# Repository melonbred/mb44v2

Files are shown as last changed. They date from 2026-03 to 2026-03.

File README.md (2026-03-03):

# MB-44 v2

MB-44 v2 Hero

## Introduction

The MB-44 is a 12.75u layout 0.5u blocker separating spacebars from the arrow cluster similar to typical 65% layout.

Version 2 is a refresh of the original project that ran in April 2021, updating the case and PCB design.

This repository includes resources for the PCB mainboard and switch plate for the MB-44 v2. Assets of the case are also available for render purposes only and are not intended for manufacturing.

## Improvements

The following are improvements made to the original MB-44:

- Effective key height (EKH) reduced from 24.6mm to 22.2mm
- PCB updated to STM32 from ATmega MCU.
- Updated from C3 variant of the Unified Daughter Board (UDB) to the S1 variant.
- PCB and bottom case cavity reduced to eliminate unnecessary reverberations.
- Brass interior cover plate and accent weight to provide some sound dampening and cover for the UDB cable.
- Plate mounting uses Geon's tadpoles.

## Keyboard Layout

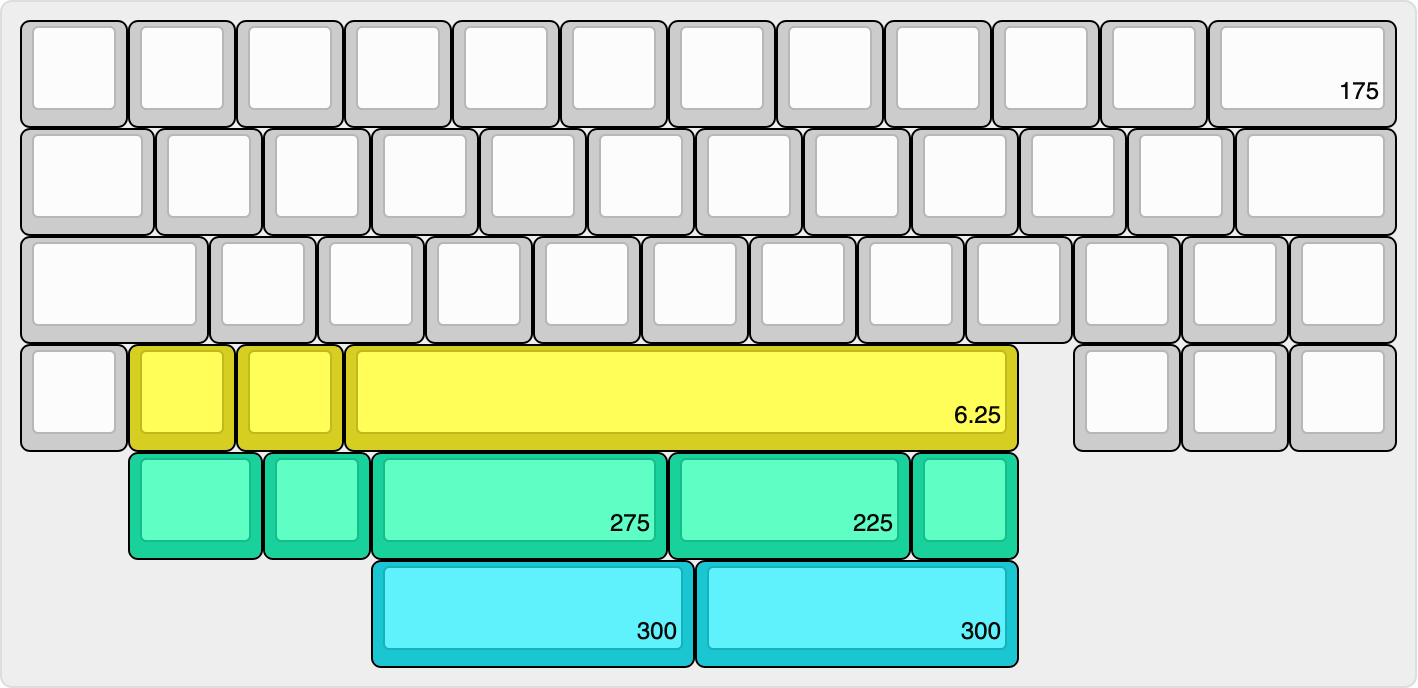
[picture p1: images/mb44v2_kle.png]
MB-44 v2 Keyboard Layout


## Information

Please note that users that would intend to use the resources in this repository is shall review all files prior to any sort of production or manufacturing. The author of this repository does not provide warranty and has no liability for how these resources are used.

Vial firmware has been compiled for for the PCB included in this repository. Firmware source is available [here](https://github.com/vial-kb/vial-qmk/tree/vial/keyboards/melonbred/mb44v2).

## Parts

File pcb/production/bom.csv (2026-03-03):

Designator | Footprint | Quantity | Value | LCSC Part #
C1, C2, C3, C4, C8, C9 | 402 | 6 | 100nF | C307331
C5 | 402 | 1 | 4.7uF | C23733
C6, C7 | 402 | 2 | 1uF | C52923
D1, D10, D11, D12, D13, D14, D15, D16, D17, D18, D19, D2, D20, D21, D22, D23, D24, D25, D26, D27, D28, D29, D3, D30, D31, D32, D33, D34, D35, D36, D37, D38, D39, D4, D40, D41, D42, D43, D46, D47, D48, D5, D6, D7, D8, D9 | D_SOD-523 | 46 | D_Small | C727112
J1 | Molex_Pico-EZmate_78171-0004_1x04-1MP_P1.20mm_Vertical | 1 | Conn_01x04_MountingPin | C528030
R1 | 402 | 1 | 10k | C25744
SW1, SW2 | SW_SPST_SKQG_WithStem | 2 | SW_Push | C318884
U1 | LQFP-48_7x7mm_P0.5mm | 1 | STM32F072CBTx | C81720
U2 | SOT-23-3 | 1 | XC6206PxxxMR | C5446

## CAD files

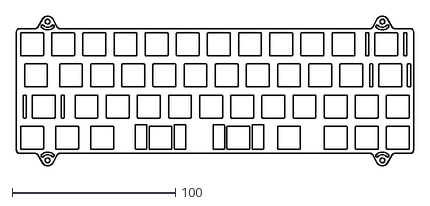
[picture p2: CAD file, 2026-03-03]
plate/mb44v2_plate_275200.dxf
242.9 x 91.7

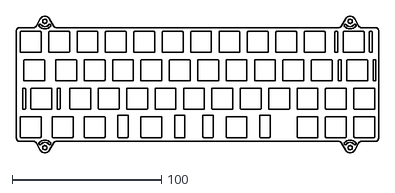
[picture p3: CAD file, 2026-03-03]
plate/mb44v2_plate_300.dxf
242.9 x 91.7

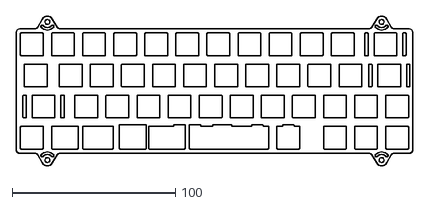
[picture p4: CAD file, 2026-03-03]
plate/mb44v2_plate_universal.dxf
242.9 x 91.7

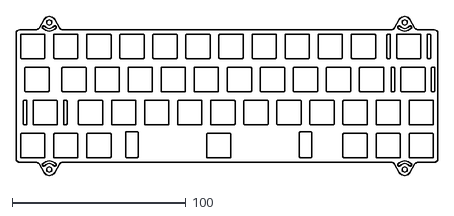
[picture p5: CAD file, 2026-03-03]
plate/mb44v2_plate_625.dxf
242.9 x 91.7

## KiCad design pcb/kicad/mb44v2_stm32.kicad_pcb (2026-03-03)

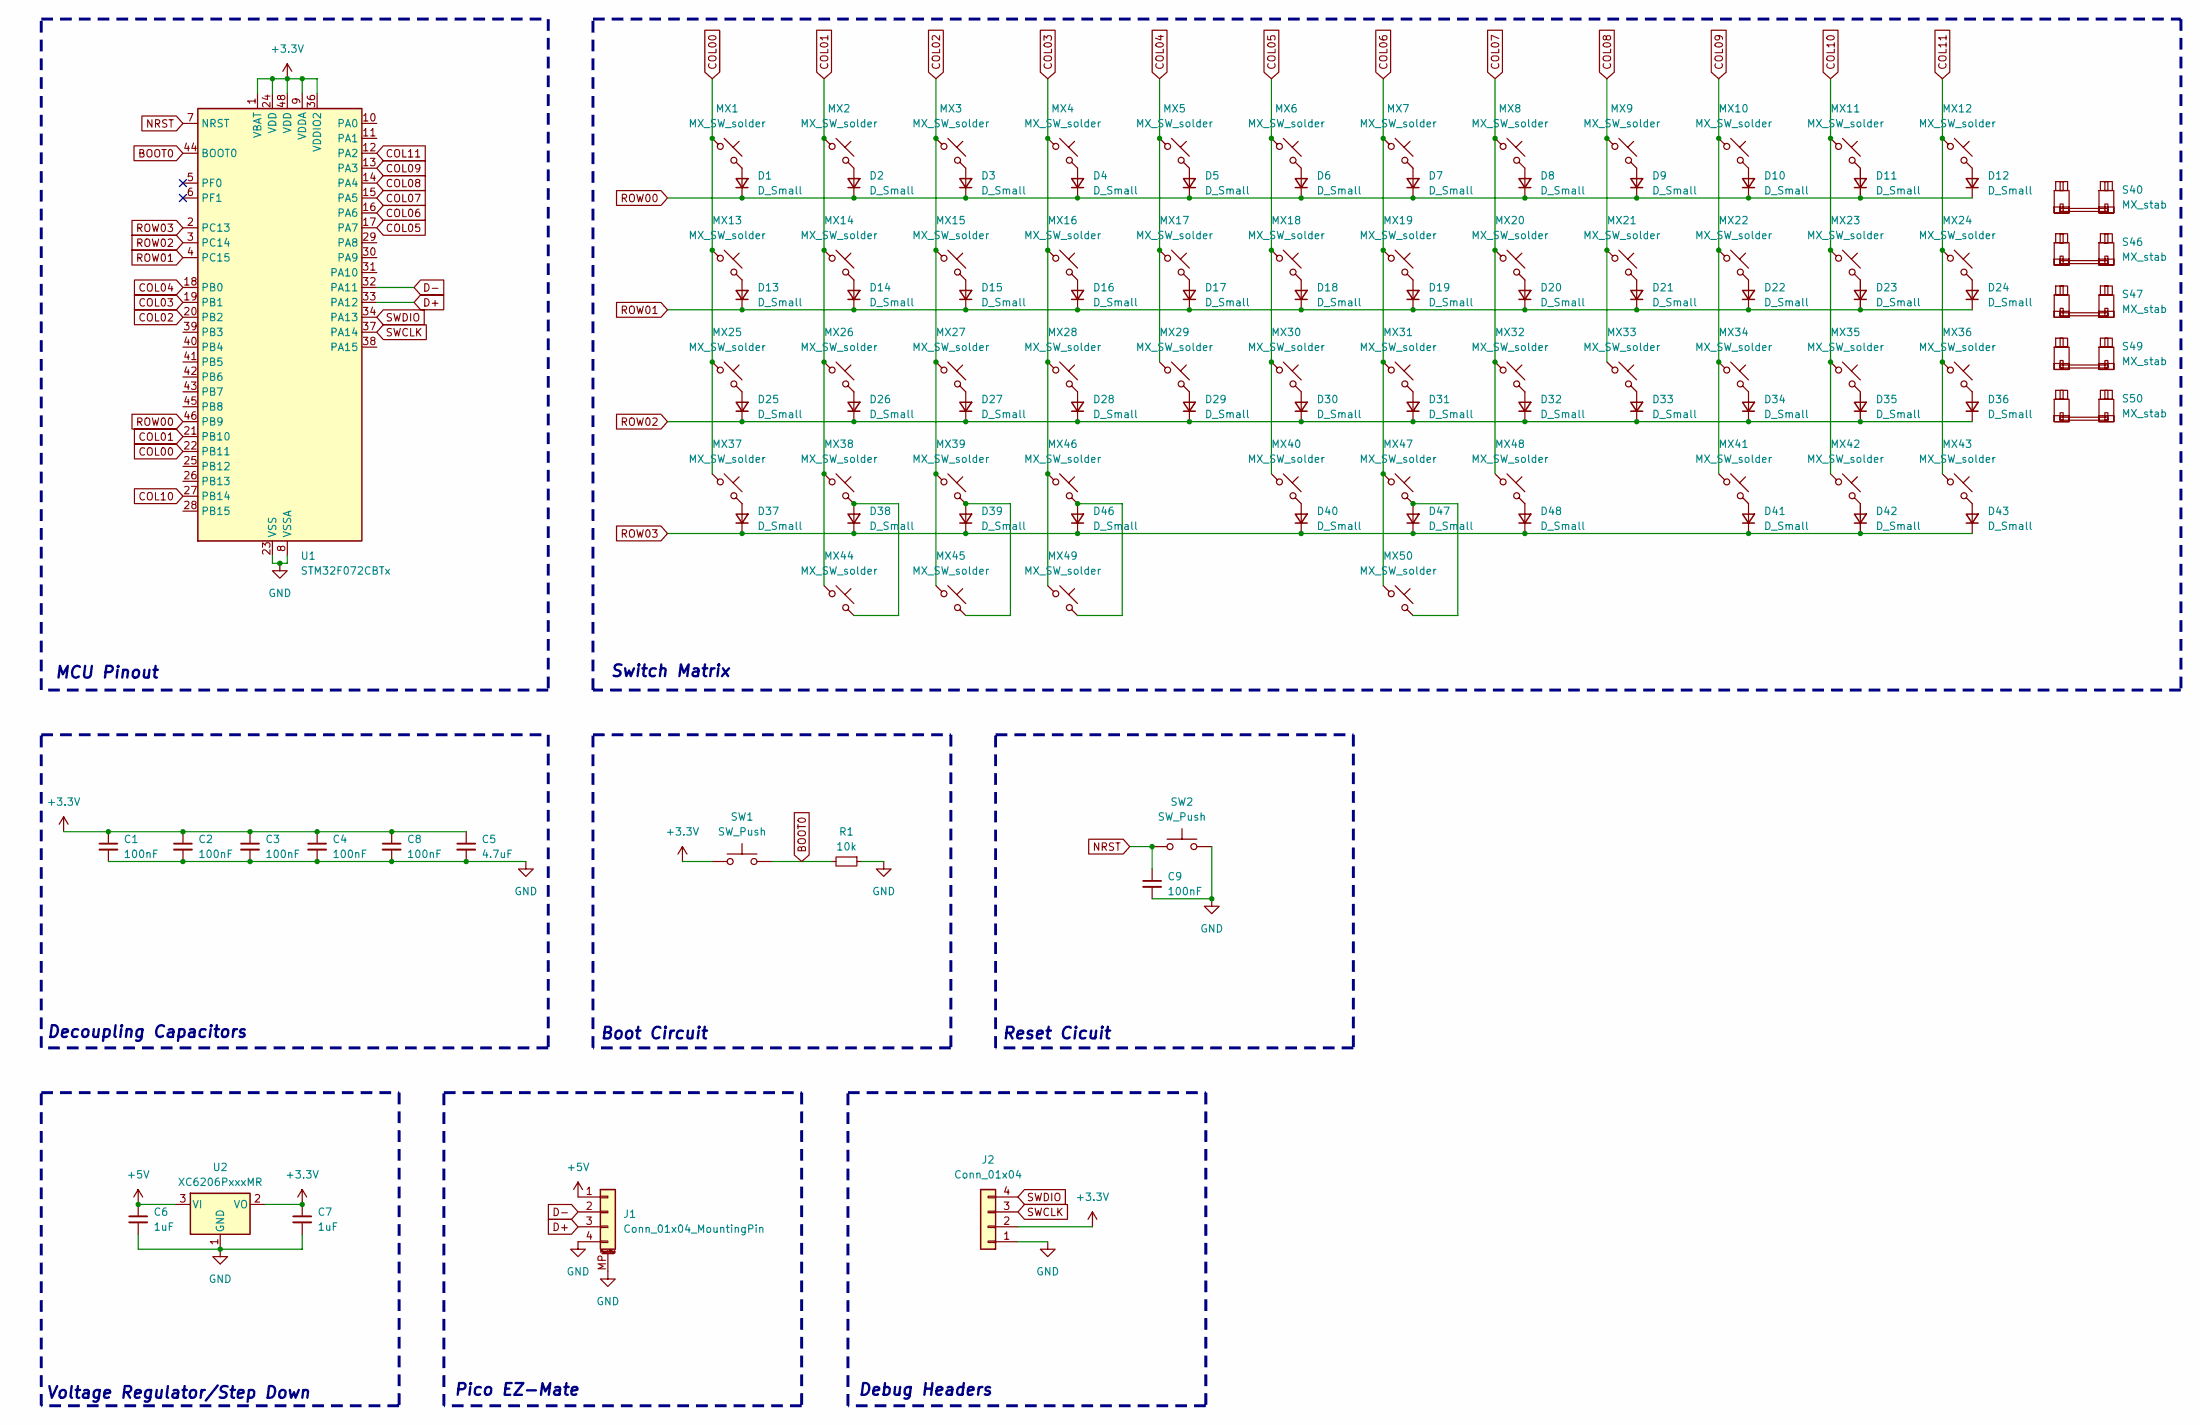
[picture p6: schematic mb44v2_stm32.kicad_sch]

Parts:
C1, C2, C3, C4, C8, C9: 100nF; C_0402_1005Metric; LCSC C307331
C5: 4.7uF; C_0402_1005Metric; LCSC C23733
C6, C7: 1uF; C_0402_1005Metric; LCSC C52923
D1, D2, D3, D4, D5, D6, D7, D8, D9, D10, D11, D12, D13, D14, D15, D16, D17, D18, D19, D20, D21, D22, D23, D24, D25, D26, D27, D28, D29, D30, D31, D32, D33, D34, D35, D36, D37, D38, D39, D40, D41, D42, D43, D46, D47: D_Small; D_SOD-523; LCSC Part C727112
D48: D_Small; D_SOD-523; LCSC C727112
J1: Conn_01x04_MountingPin; Molex_Pico-EZmate_78171-0004_1x04-1MP_P1.20mm_Vertical; LCSC C2997427
J2: Conn_01x04; PinHeader_1x04_P2.00mm_Vertical
MX1, MX2, MX3, MX4, MX5, MX6, MX7, MX8, MX9, MX10, MX11, MX14, MX15, MX16, MX17, MX18, MX19, MX20, MX21, MX22, MX23, MX26, MX27, MX28, MX29, MX30, MX31, MX32, MX33, MX34, MX35, MX36, MX37, MX38, MX39, MX40, MX41, MX42, MX43, MX45, MX46, MX47, MX48, MX49, MX50: MX_SW_solder; SW_MX_1u
MX12, MX25: MX_SW_solder; SW_MX_1.75u
MX13, MX44: MX_SW_solder; SW_MX_1.25u
MX24: MX_SW_solder; SW_MX_1.5u
R1: 10k; R_0402_1005Metric; LCSC C25744
S40: MX_stab; STAB_MX_P_6.25u
S46: MX_stab; STAB_MX_P_2.75u
S47: MX_stab; STAB_MX_P_2.25u
S49, S50: MX_stab; STAB_MX_P_3u
SW1, SW2: SW_Push; SW_SPST_SKQG_WithStem; LCSC C318884
U1: STM32F072CBTx; LQFP-48_7x7mm_P0.5mm; LCSC C81720
U2: XC6206PxxxMR; SOT-23-3; LCSC C5446

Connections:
+3.3V: C1.1, C2.1, C3.1, C4.1, C5.1, C7.1, C8.1, J2.2, SW1.1, U1.1 (VBAT), U1.9 (VDDA), U1.24 (VDD), U1.36 (VDDIO2), U1.48 (VDD), U2.2 (VO)
+5V: C6.1, J1.1, U2.3 (VI)
BOOT0: R1.2, SW1.2, U1.44 (BOOT0)
COL00: MX1.1, MX13.1, MX25.1, MX37.1, U1.22 (PB11)
COL01: MX2.1, MX14.1, MX26.1, MX38.1, MX44.1, U1.21 (PB10)
COL02: MX3.1, MX15.1, MX27.1, MX39.1, MX45.1, U1.20 (PB2)
COL03: MX4.1, MX16.1, MX28.1, MX46.1, MX49.1, U1.19 (PB1)
COL04: MX5.1, MX17.1, MX29.1, U1.18 (PB0)
COL05: MX6.1, MX18.1, MX30.1, MX40.1, U1.17 (PA7)
COL06: MX7.1, MX19.1, MX31.1, MX47.1, MX50.1, U1.16 (PA6)
COL07: MX8.1, MX20.1, MX32.1, MX48.1, U1.15 (PA5)
COL08: MX9.1, MX21.1, MX33.1, U1.14 (PA4)
COL09: MX10.1, MX22.1, MX34.1, MX41.1, U1.13 (PA3)
COL10: MX11.1, MX23.1, MX35.1, MX42.1, U1.27 (PB14)
COL11: MX12.1, MX24.1, MX36.1, MX43.1, U1.12 (PA2)
D+: J1.3, U1.33 (PA12)
D-: J1.2, U1.32 (PA11)
GND: C1.2, C2.2, C3.2, C4.2, C5.2, C6.2, C7.2, C8.2, C9.2, J1.4, J1.MP (MountPin), J2.1, R1.1, SW2.2, U1.8 (VSSA), U1.23 (VSS), U1.35 (VSS), U1.47 (VSS), U2.1 (GND)
NRST: C9.1, SW2.1, U1.7 (NRST)
unnamed: D1.2 (A), MX1.2
unnamed: D2.2 (A), MX2.2
unnamed: D3.2 (A), MX3.2
unnamed: D4.2 (A), MX4.2
unnamed: D5.2 (A), MX5.2
unnamed: D6.2 (A), MX6.2
unnamed: D7.2 (A), MX7.2
unnamed: D8.2 (A), MX8.2
unnamed: D9.2 (A), MX9.2
unnamed: D10.2 (A), MX10.2
unnamed: D11.2 (A), MX11.2
unnamed: D12.2 (A), MX12.2
unnamed: D13.2 (A), MX13.2
unnamed: D14.2 (A), MX14.2
unnamed: D15.2 (A), MX15.2
unnamed: D16.2 (A), MX16.2
unnamed: D17.2 (A), MX17.2
unnamed: D18.2 (A), MX18.2
unnamed: D19.2 (A), MX19.2
unnamed: D20.2 (A), MX20.2
unnamed: D21.2 (A), MX21.2
unnamed: D22.2 (A), MX22.2
unnamed: D23.2 (A), MX23.2
unnamed: D24.2 (A), MX24.2
unnamed: D25.2 (A), MX25.2
unnamed: D26.2 (A), MX26.2
unnamed: D27.2 (A), MX27.2
unnamed: D28.2 (A), MX28.2
unnamed: D29.2 (A), MX29.2
unnamed: D30.2 (A), MX30.2
unnamed: D31.2 (A), MX31.2
unnamed: D32.2 (A), MX32.2
unnamed: D33.2 (A), MX33.2
unnamed: D34.2 (A), MX34.2
unnamed: D35.2 (A), MX35.2
unnamed: D36.2 (A), MX36.2
unnamed: D37.2 (A), MX37.2
unnamed: D38.2 (A), MX38.2, MX44.2
unnamed: D39.2 (A), MX39.2, MX45.2
unnamed: D40.2 (A), MX40.2
unnamed: D41.2 (A), MX41.2
unnamed: D42.2 (A), MX42.2
unnamed: D43.2 (A), MX43.2
unnamed: D46.2 (A), MX46.2, MX49.2
unnamed: D47.2 (A), MX47.2, MX50.2
unnamed: D48.2 (A), MX48.2
ROW00: D1.1 (K), D2.1 (K), D3.1 (K), D4.1 (K), D5.1 (K), D6.1 (K), D7.1 (K), D8.1 (K), D9.1 (K), D10.1 (K), D11.1 (K), D12.1 (K), U1.46 (PB9)
ROW01: D13.1 (K), D14.1 (K), D15.1 (K), D16.1 (K), D17.1 (K), D18.1 (K), D19.1 (K), D20.1 (K), D21.1 (K), D22.1 (K), D23.1 (K), D24.1 (K), U1.4 (PC15)
ROW02: D25.1 (K), D26.1 (K), D27.1 (K), D28.1 (K), D29.1 (K), D30.1 (K), D31.1 (K), D32.1 (K), D33.1 (K), D34.1 (K), D35.1 (K), D36.1 (K), U1.3 (PC14)
ROW03: D37.1 (K), D38.1 (K), D39.1 (K), D40.1 (K), D41.1 (K), D42.1 (K), D43.1 (K), D46.1 (K), D47.1 (K), D48.1 (K), U1.2 (PC13)
SWCLK: J2.3, U1.37 (PA14)
SWDIO: J2.4, U1.34 (PA13)

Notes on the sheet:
Reset Cicuit
Debug Headers
Pico EZ-Mate
Voltage Regulator/Step Down
MCU Pinout
Switch Matrix
Boot Circuit
Decoupling Capacitors

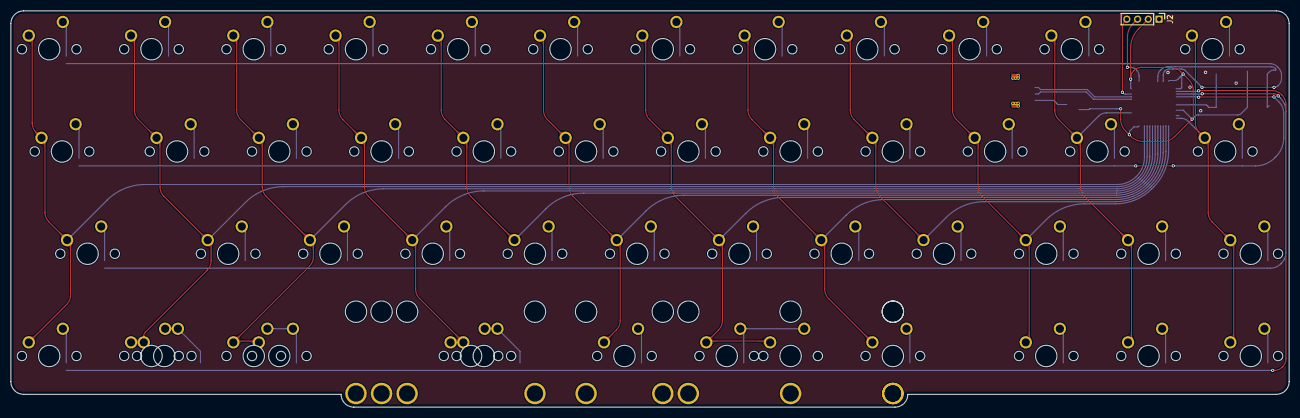
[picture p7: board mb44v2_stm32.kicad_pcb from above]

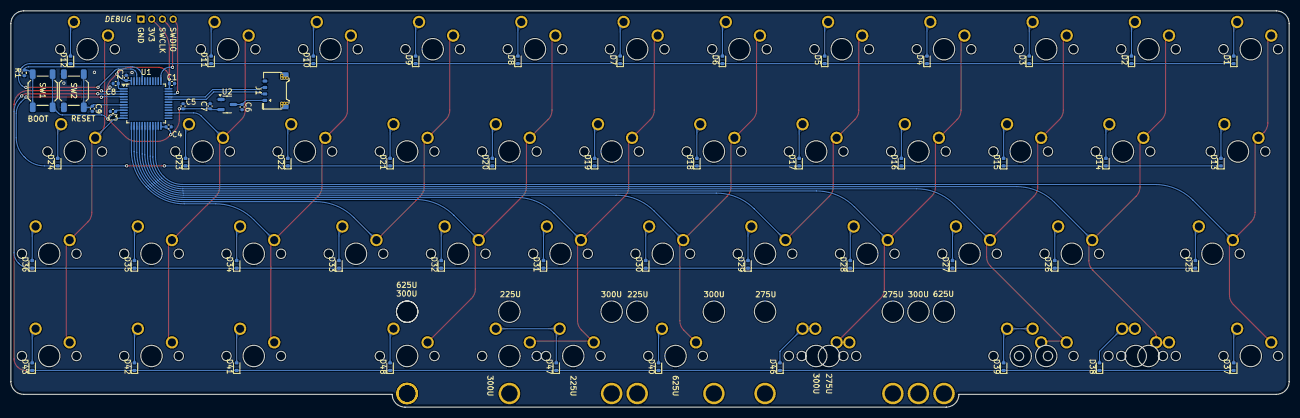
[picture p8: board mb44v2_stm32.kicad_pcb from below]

Board: 2 copper layers, 238.1 x 73.8 mm, 117 parts (61 on the bottom side), 71 nets.
